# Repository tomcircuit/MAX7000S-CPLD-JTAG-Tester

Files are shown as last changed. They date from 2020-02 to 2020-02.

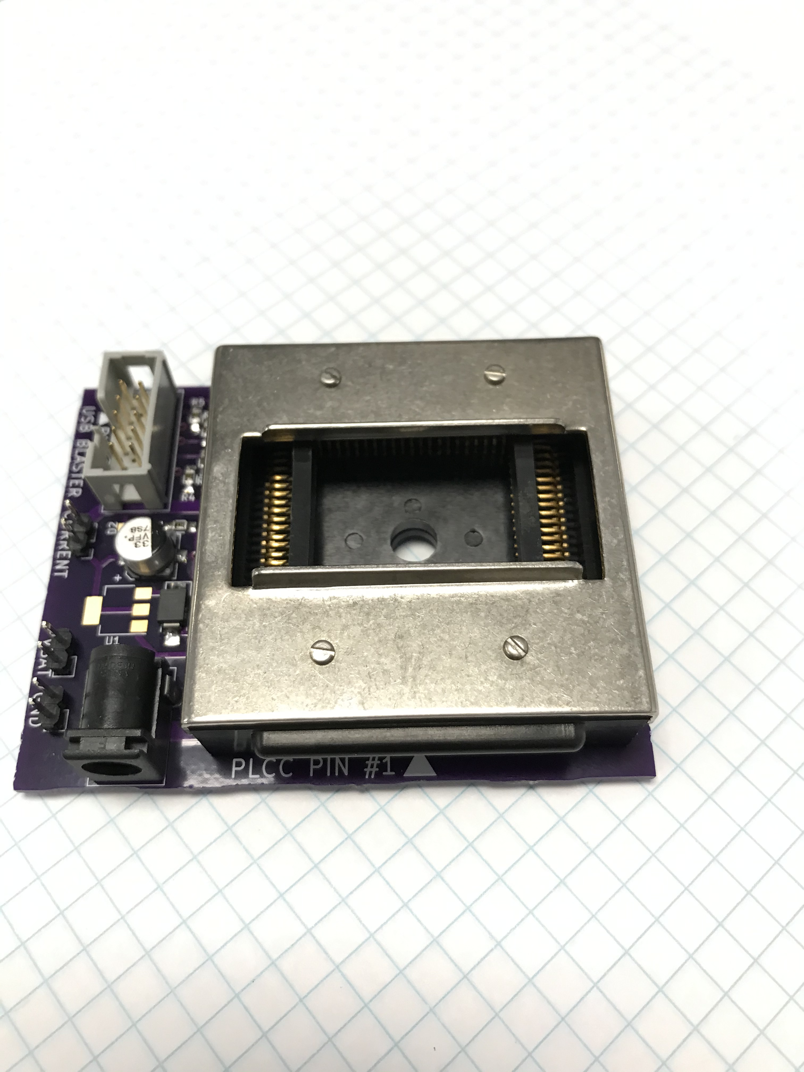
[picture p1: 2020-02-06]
media/IMG_4216.jpg

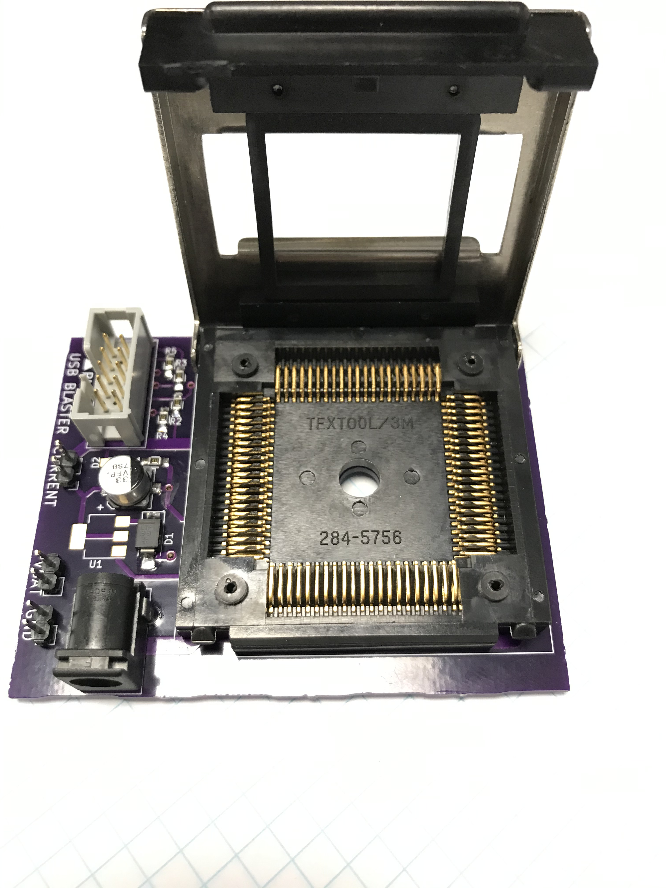
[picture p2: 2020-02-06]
media/IMG_4215.jpg

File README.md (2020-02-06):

# MAX7000S CPLD JTAG Tester

This set of design files pertains to a testboard for EPM7128SLx84 CPLDs

I am a big fan of the EPM7128SLC84 CPLD device. It supports 5V I/O for retroputing projects,
has enough macrocells to support medium complexity projects (e.g. glue for hd6309 SBC), etc.
This device is EOL from Altera (Intel) but can be found on the 'gray-market' (e.g. eBay).
However, many of the devices found from such sellers are not usable because the JTAG pins
have been re-assigned to I/O. Once this is done, the CPLD can only be reset to factory
default state with hard-to-find Altera parallel programming equipment. 

So, this project was born to allow CPLD devices to be temporarily connected to an Altera USB 
blaster (or compatible) to see if the JTAG is operational. A 3M PLCC socket is used for this
project, which might be a bit hard to find, but is well worth the effort.

More up-to-date information on the SBC can be found on the Hackaday project page:
####

This work is licensed under the Creative Commons Attribution-ShareAlike 4.0 International License. 
To view a copy of this license, visit http://creativecommons.org/licenses/by-sa/4.0/.

Tom LeMense
2/6/2020

tomcircuit@gmail.com
@TomLeMense

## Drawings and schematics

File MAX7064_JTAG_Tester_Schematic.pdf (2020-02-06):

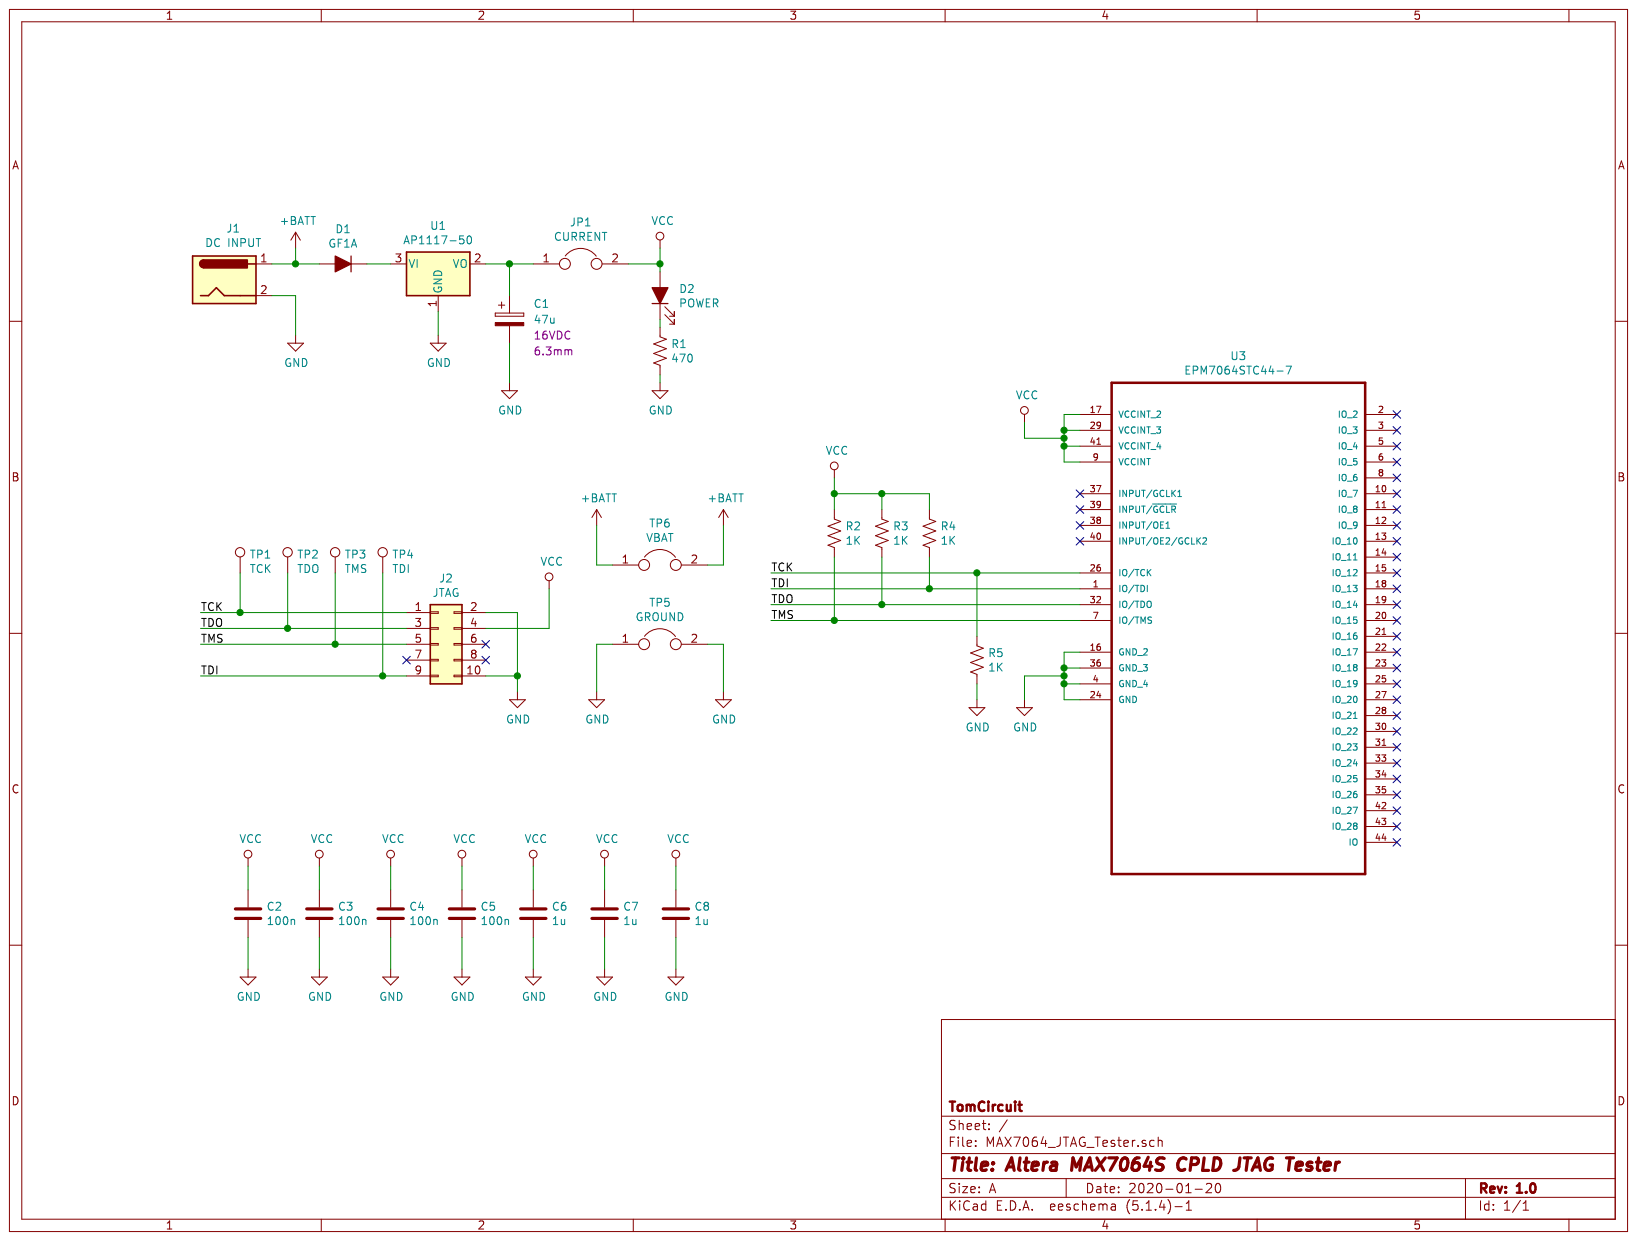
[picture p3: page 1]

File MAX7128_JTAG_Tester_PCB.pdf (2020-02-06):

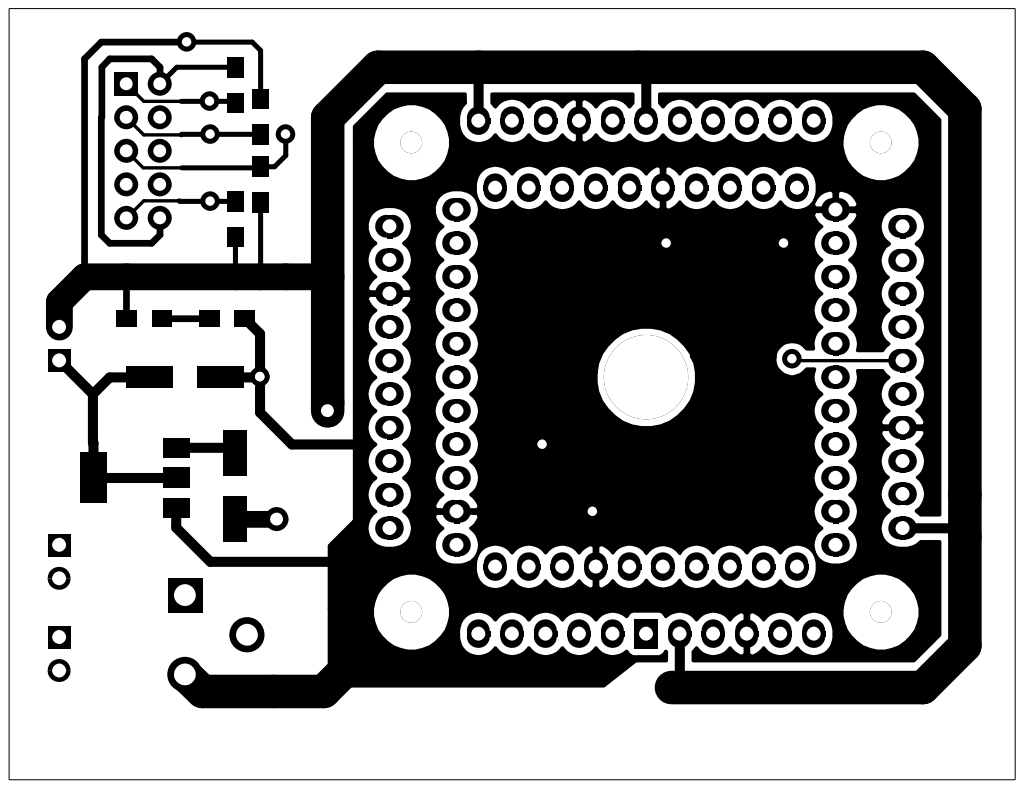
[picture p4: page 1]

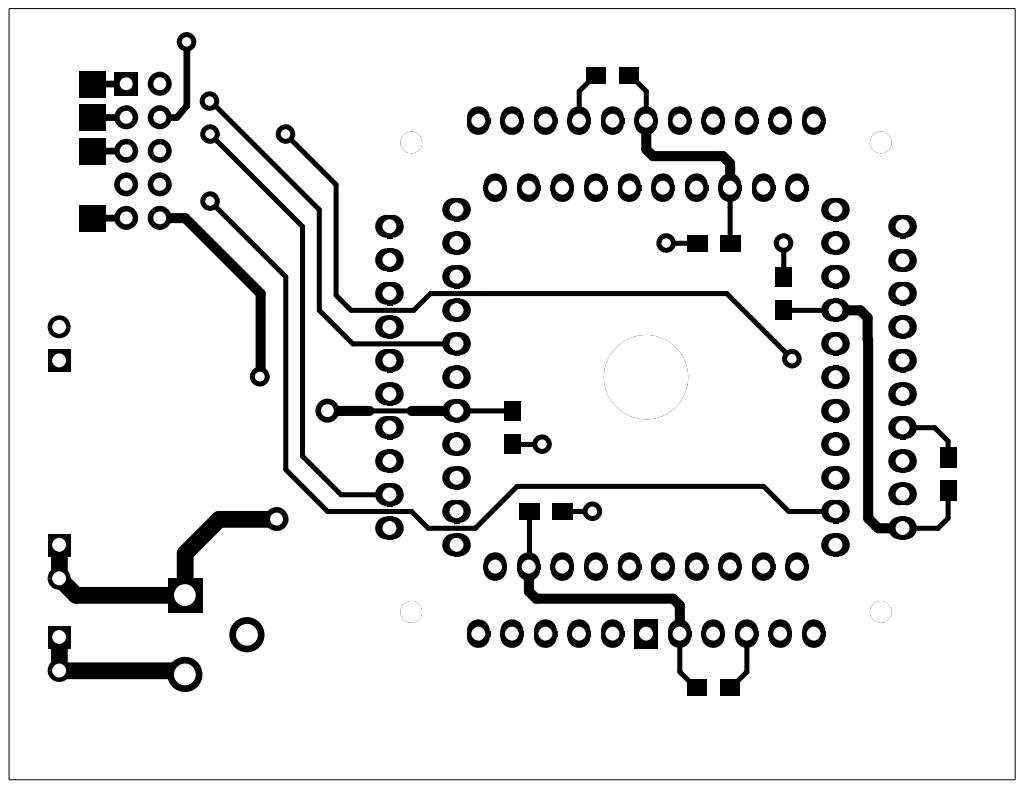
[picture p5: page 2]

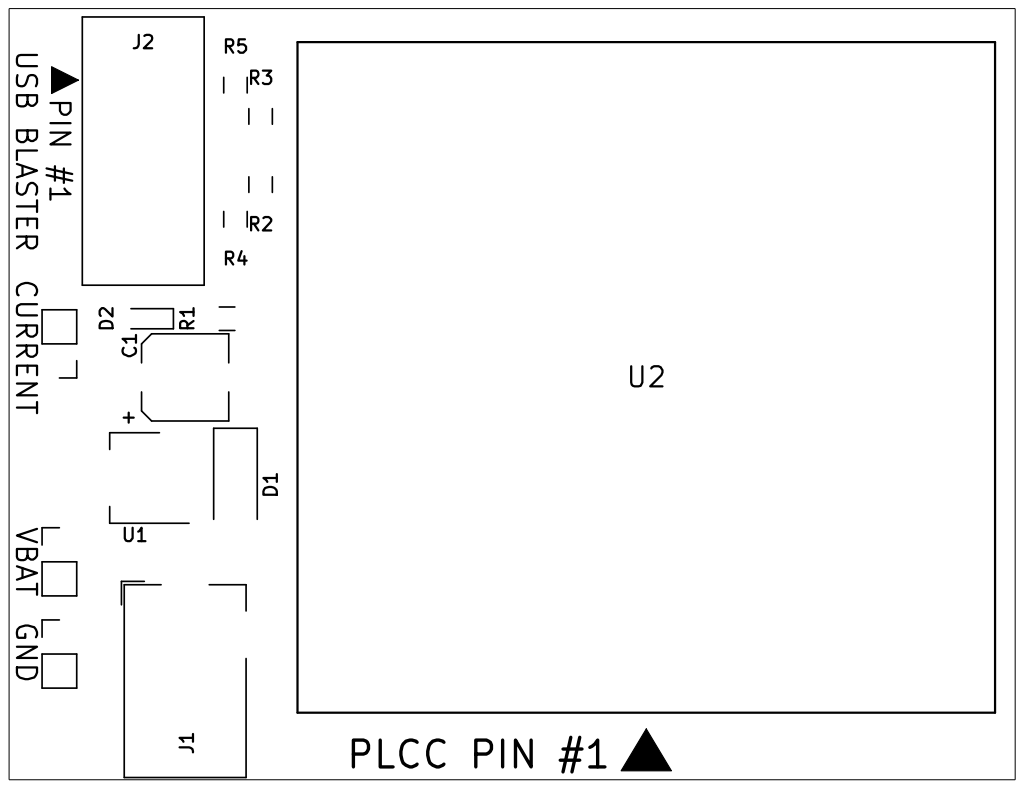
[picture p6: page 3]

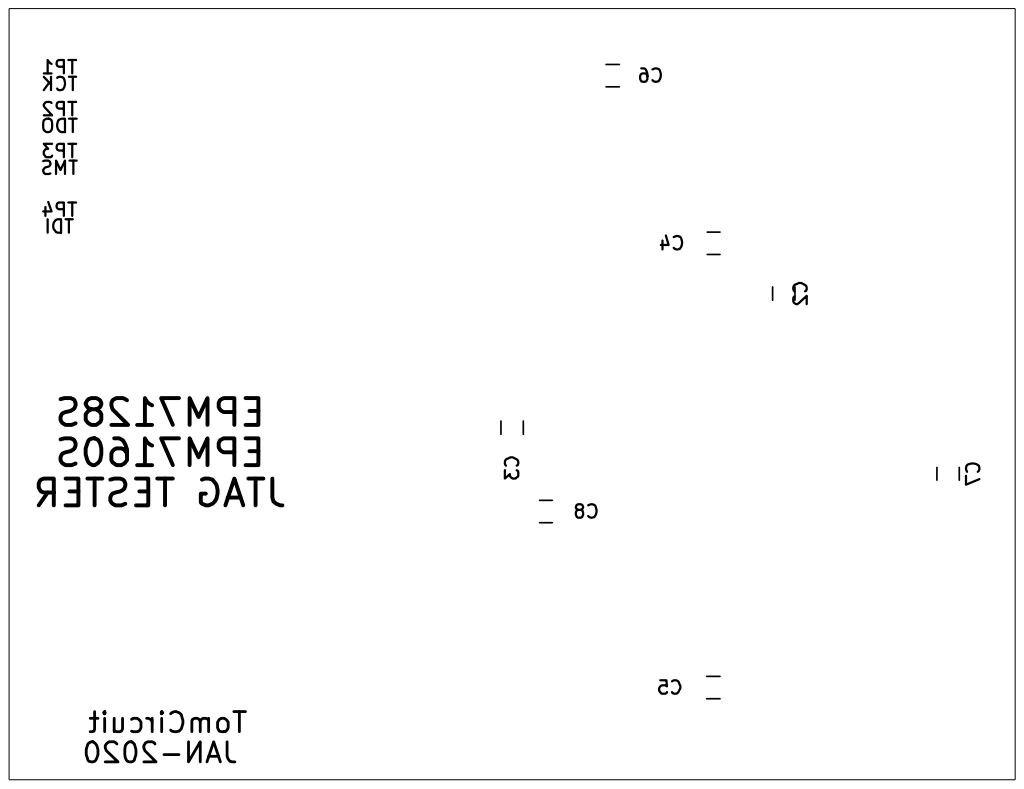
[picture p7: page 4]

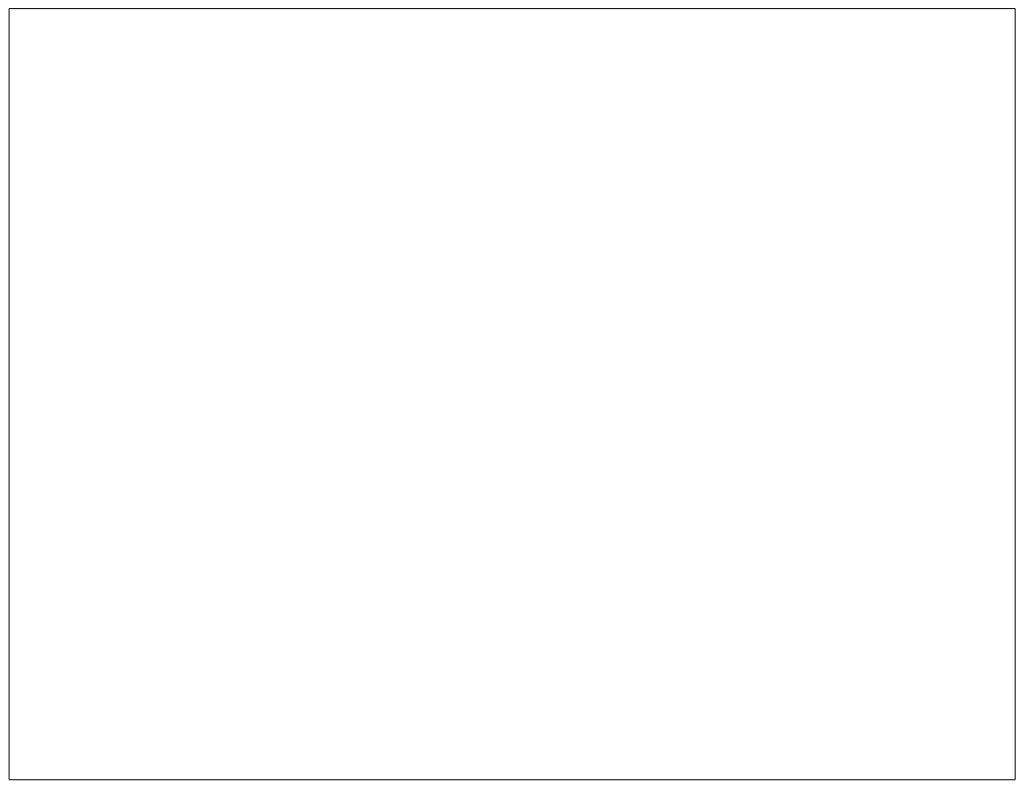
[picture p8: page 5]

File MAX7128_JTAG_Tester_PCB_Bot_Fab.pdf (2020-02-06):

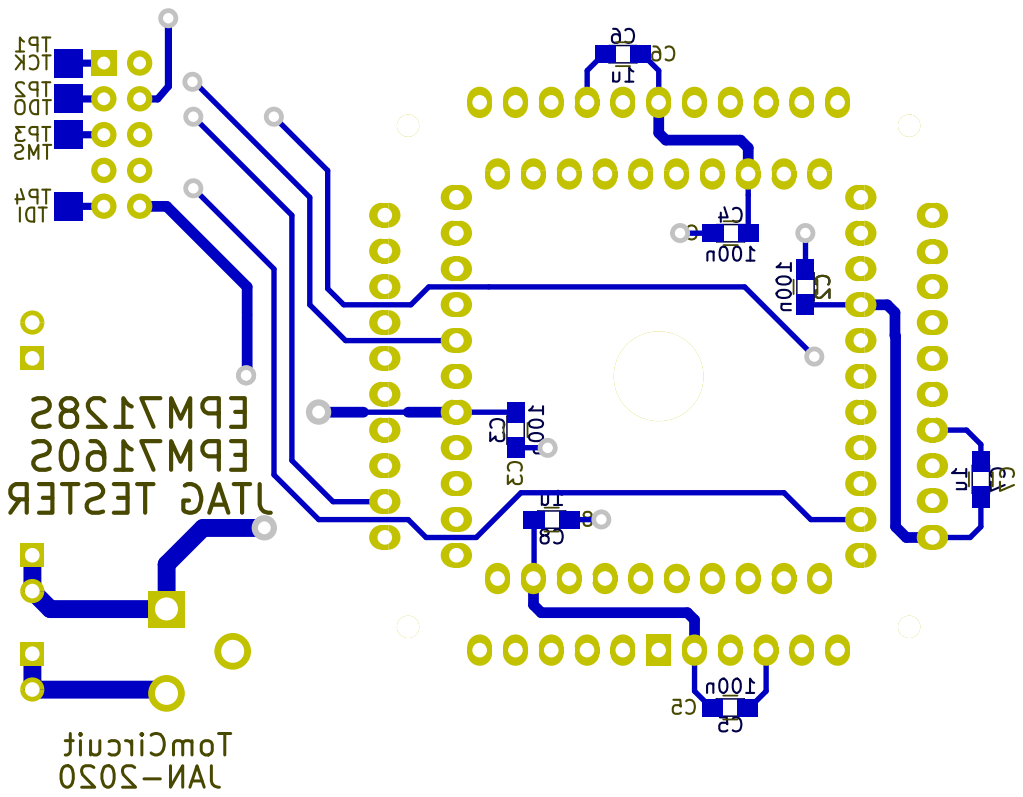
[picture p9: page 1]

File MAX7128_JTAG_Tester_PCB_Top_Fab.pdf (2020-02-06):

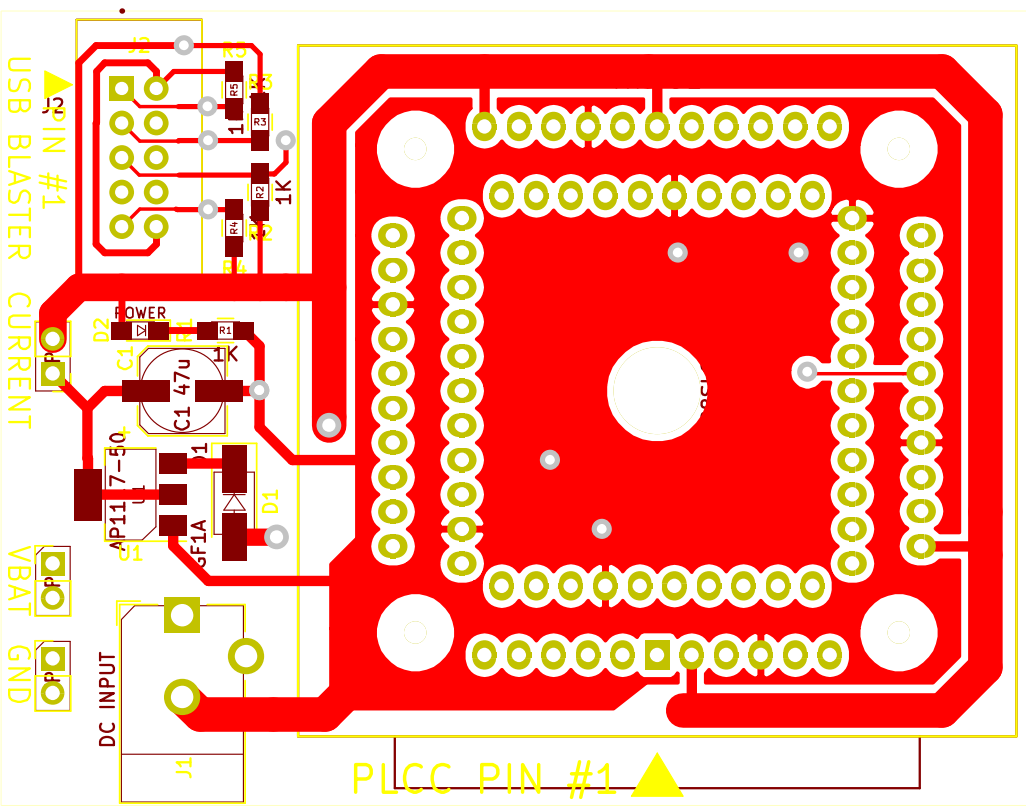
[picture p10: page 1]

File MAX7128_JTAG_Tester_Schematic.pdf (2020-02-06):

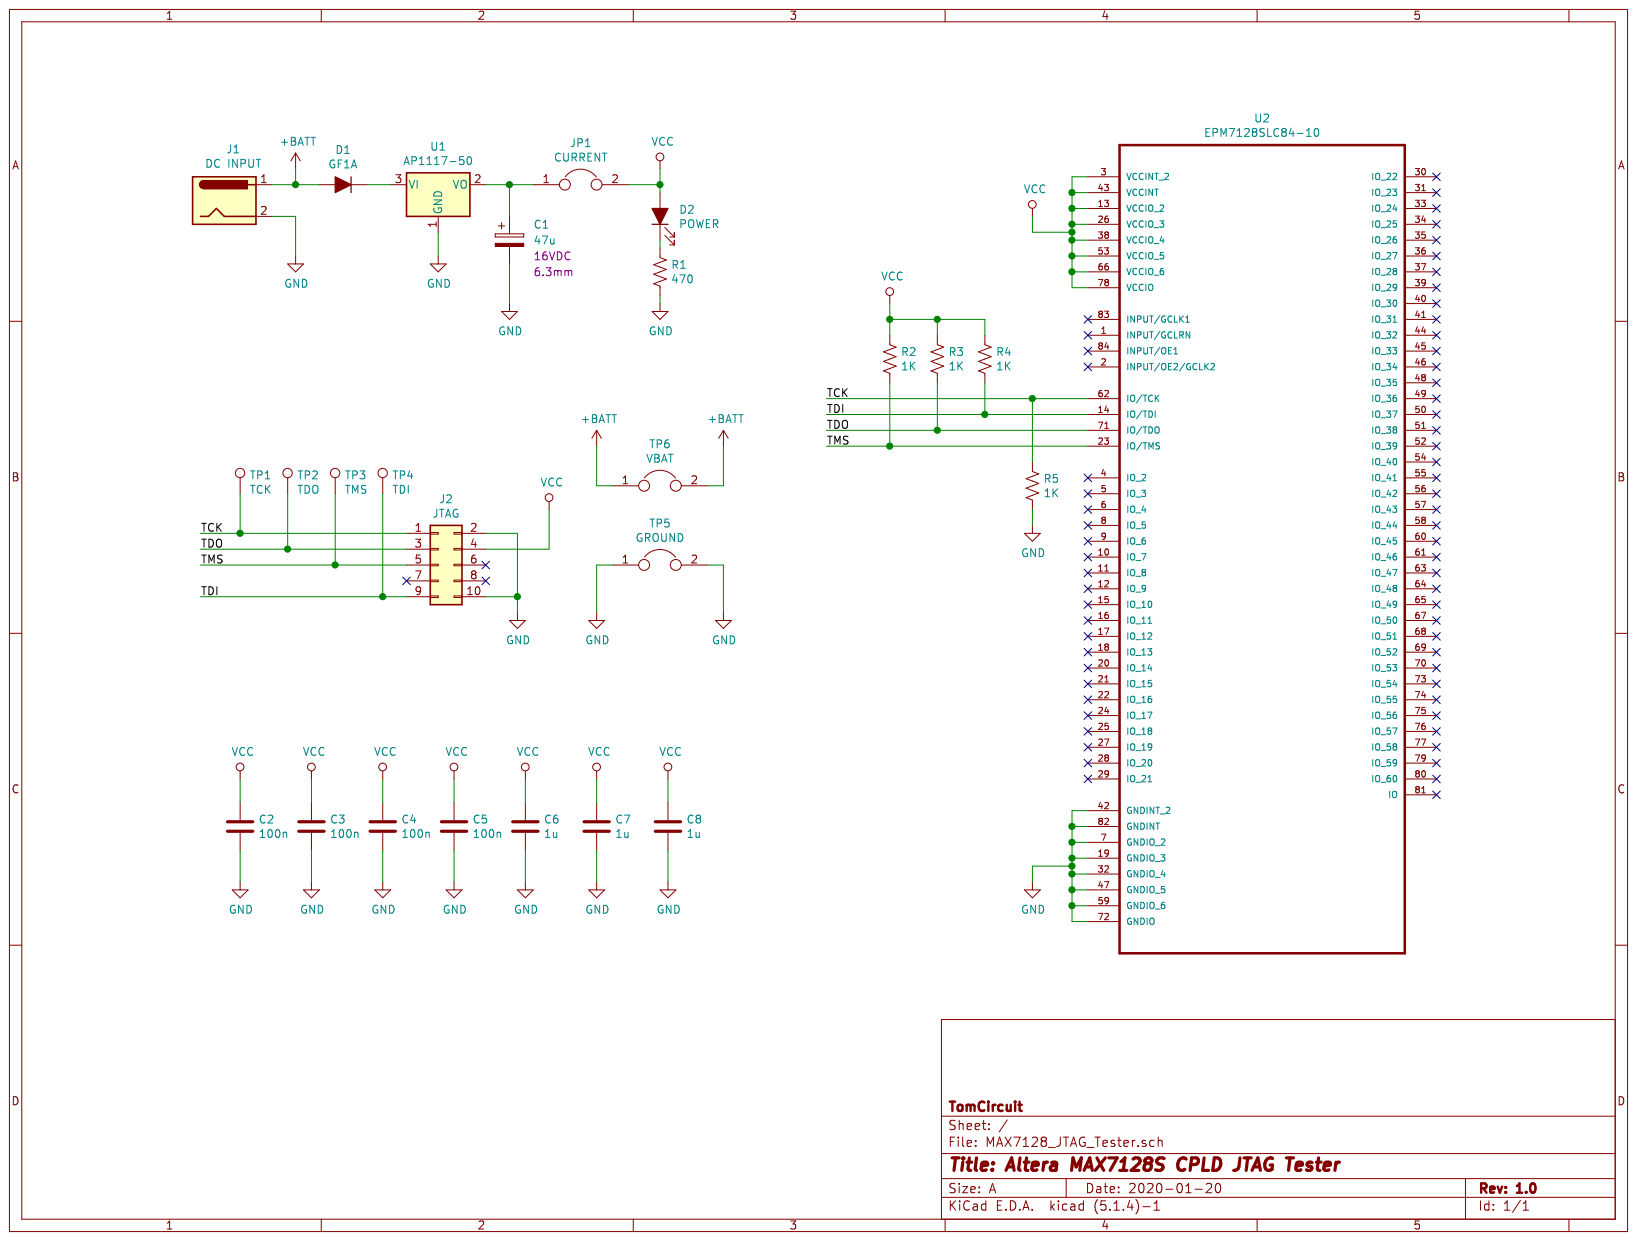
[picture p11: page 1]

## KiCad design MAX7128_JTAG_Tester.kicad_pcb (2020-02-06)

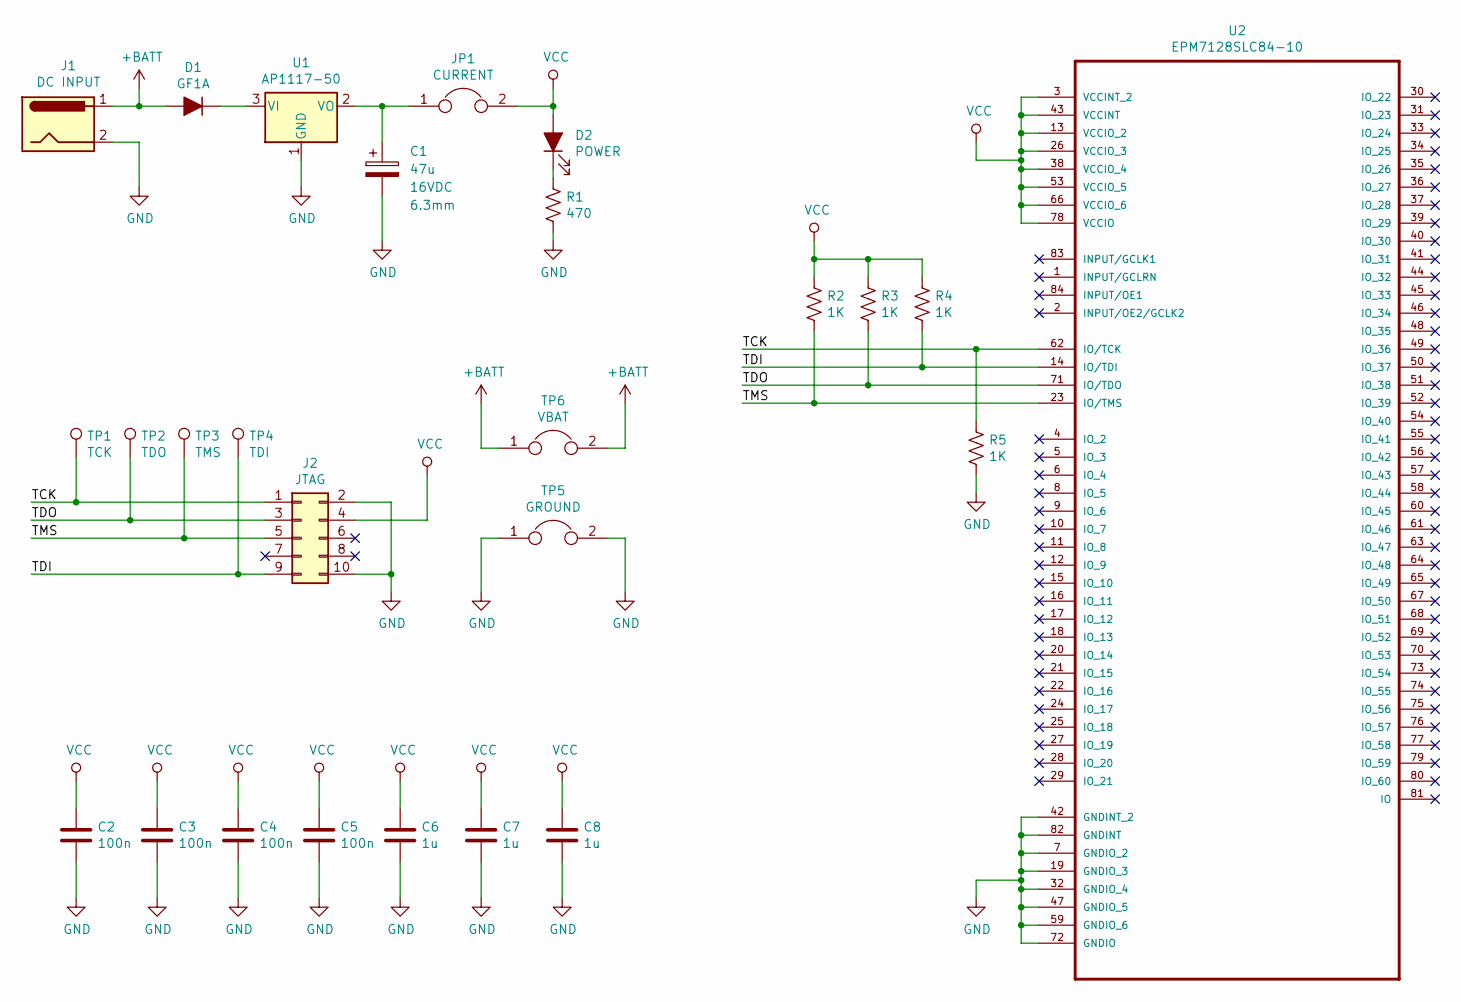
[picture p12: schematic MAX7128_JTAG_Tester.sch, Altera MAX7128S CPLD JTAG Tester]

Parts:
C1: 47u; CP_Elec_6.3x4.5; Voltage 16VDC
C2, C3, C4, C5: 100n; C_0603_HandSoldering
C6, C7, C8: 1u; C_0603_HandSoldering
D1: GF1A; D_SMA_Handsoldering
D2: POWER; LED_0805_HandSoldering
J1: DC INPUT; Barrel_Jack_CUI_PJ-102AH
J2: JTAG; SDL-110-X-XX_2x05
JP1: CURRENT; Pin_Header_Straight_1x02_Pitch2.54mm
R1: 470; R_0805_HandSoldering
R2, R3, R4, R5: 1K; R_0805_HandSoldering
TP1: TCK; Measurement_Point_Square-SMD-Pad_Big
TP2: TDO; Measurement_Point_Square-SMD-Pad_Big
TP3: TMS; Measurement_Point_Square-SMD-Pad_Big
TP4: TDI; Measurement_Point_Square-SMD-Pad_Big
TP5: GROUND; Pin_Header_Straight_1x02_Pitch2.54mm
TP6: VBAT; Pin_Header_Straight_1x02_Pitch2.54mm
U1: AP1117-50; SOT-223-3_TabPin2
U2: EPM7128SLC84-10; 284-5756-00-1102

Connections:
+BATT: D1.2 (A), J1.1, TP6.1, TP6.2
/TCK: J2.1, R5.1, TP1.1, U2.62 (IO/TCK)
/TDI: J2.9, R4.2, TP4.1, U2.14 (IO/TDI)
/TDO: J2.3, R3.2, TP2.1, U2.71 (IO/TDO)
/TMS: J2.5, R2.2, TP3.1, U2.23 (IO/TMS)
GND: C1.2, C2.2, C3.2, C4.2, C5.2, C6.2, C7.2, C8.2, J1.2, J2.2, J2.10, R1.2, R5.2, TP5.1, TP5.2, U1.1 (GND), U2.7 (GNDIO_2), U2.19 (GNDIO_3), U2.32 (GNDIO_4), U2.42 (GNDINT_2), U2.47 (GNDIO_5), U2.59 (GNDIO_6), U2.72 (GNDIO), U2.82 (GNDINT)
unnamed: C1.1, JP1.1, U1.2 (VO)
unnamed: D1.1 (K), U1.3 (VI)
unnamed: D2.1 (K), R1.1
VCC: C2.1, C3.1, C4.1, C5.1, C6.1, C7.1, C8.1, D2.2 (A), J2.4, JP1.2, R2.1, R3.1, R4.1, U2.3 (VCCINT_2), U2.13 (VCCIO_2), U2.26 (VCCIO_3), U2.38 (VCCIO_4), U2.43 (VCCINT), U2.53 (VCCIO_5), U2.66 (VCCIO_6), U2.78 (VCCIO)

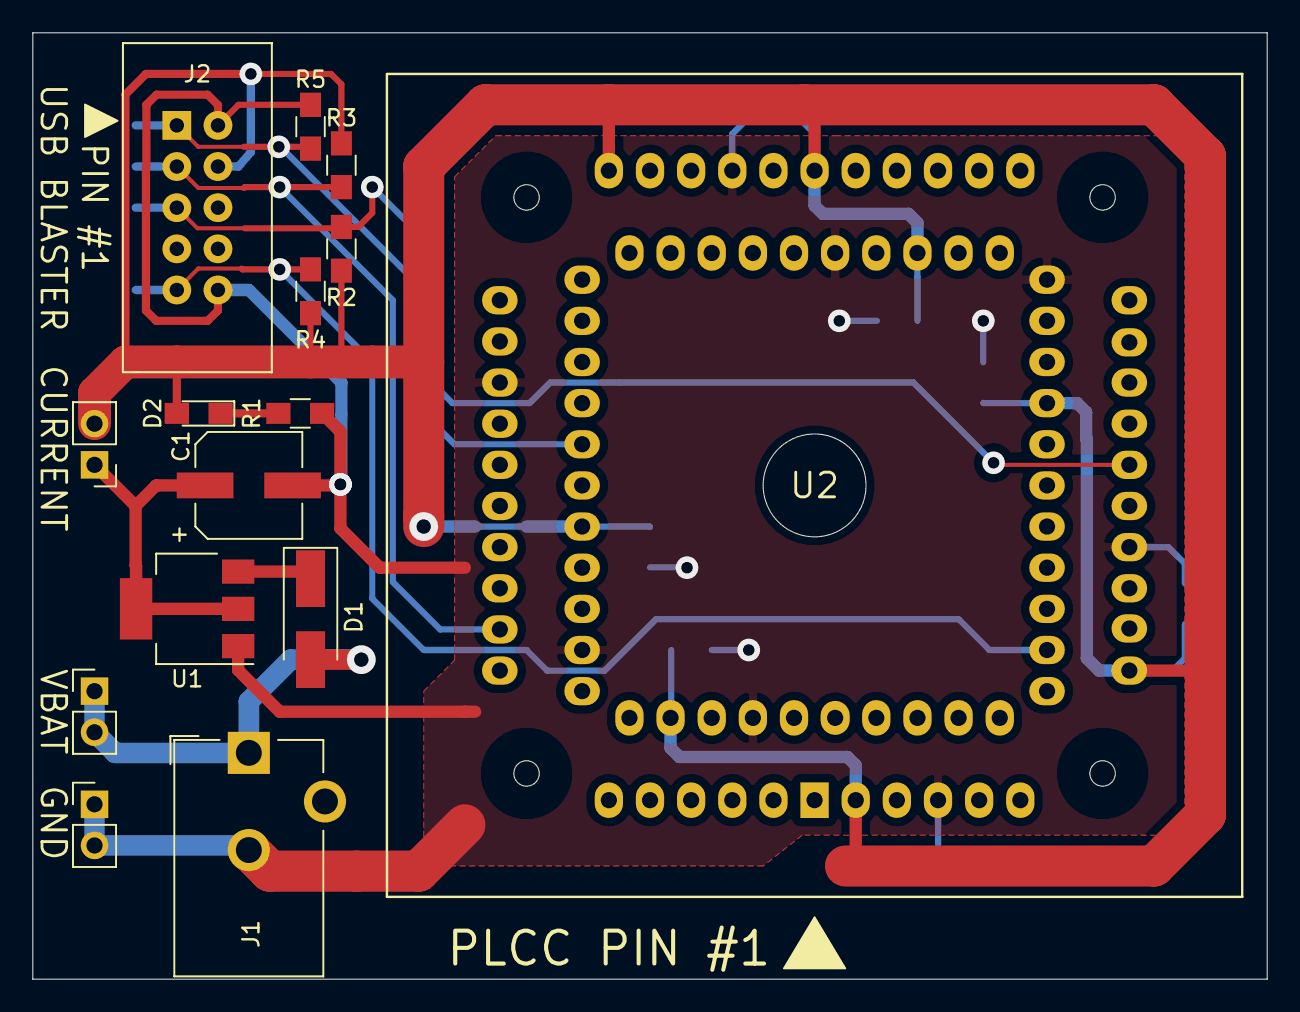
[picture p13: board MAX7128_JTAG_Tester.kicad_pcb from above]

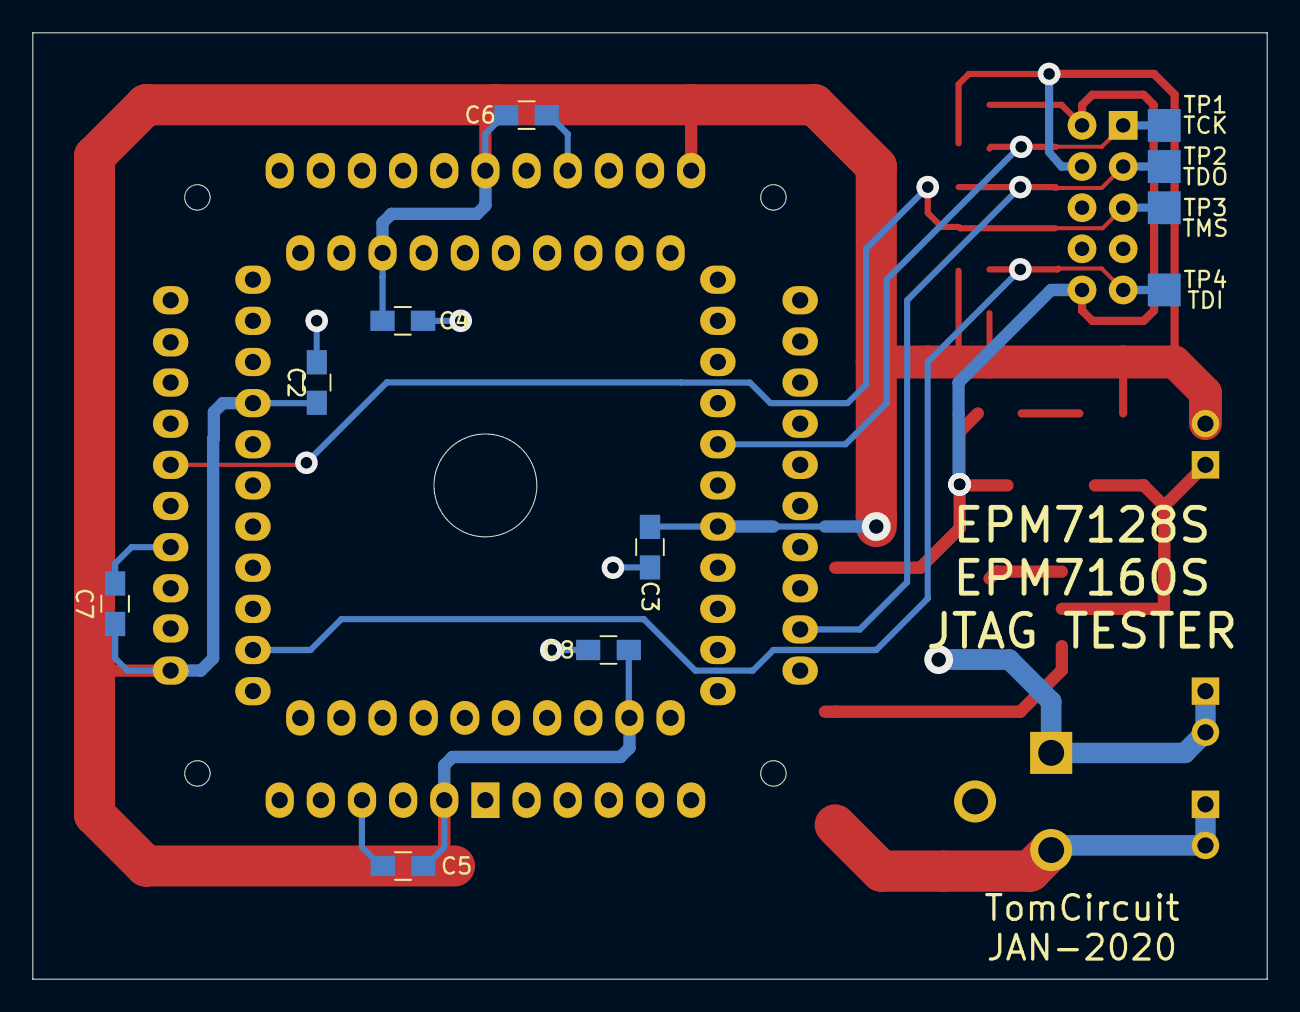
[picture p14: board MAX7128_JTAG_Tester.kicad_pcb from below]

Board: 2 copper layers, 76.2 x 58.4 mm, 26 parts (11 on the bottom side), 10 nets.

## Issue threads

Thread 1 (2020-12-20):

Enhancment

maded2, 2020-12-20:
hi Tom,
    I know your design is just a tester board.  But Sparkfun used to sell a clone of the ByteBlasterMV programmer (http://www.sparkfun.com/datasheets/DevTools/FPGA/Altera%20Programmer/Altera_Programmer-v10_Schematic.pdf).  Which maybe good to add to your board so that it can be use to unlock the EPM7128S.   I am currently researching how to do that as I've several used EPM7128SLC (PLCC84) which JTAG cannot scan from Aliexpress.

Also do you know where the nSTATUS pin is on the EPM7128S?

thanks,
eddie

tomcircuit, 2020-12-28:
Hi Eddie,
My tester board is designed to work with either a USB Blaster or ByteBlaster (real or clone) - or, really, I suppose any USB-to-JTAG adapter that you might have on hand. The ByteBlaster was the precursor to the USB Blaster. The ByteBlaster connects to a Parallel (DB25 LPT port) and relied upon some software driver to do all of the JTAG bit twiddling. I no longer have any computers with LPT ports (what a relief!) Unfortunately, neither the ByteBlaster nor the USBBlaster can unlock a MAX7000S device with disabled JTAG pins.

There is no nSTATUS pin on the MAX7000S family of devices - TDI/TDO/TCLK/TMS are all that are present.

Sorry to disappoint you!
Tom

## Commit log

2020-02-06 Initial checking
    PCB fabbed, build, and tested.
    [MAX7064_JTAG_Tester.sch, MAX7128_JTAG_Tester.kicad_pcb, MAX7128_JTAG_Tester.sch]
2020-02-06 Added assembled board photos
